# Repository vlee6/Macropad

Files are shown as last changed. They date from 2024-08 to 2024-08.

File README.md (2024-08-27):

# ATmega32U4 Macropad

For my first-ever PCB project, I've designed a 9 key low-profile macropad with a rotary encoder and oled screen. My intention was to keep costs minimal while retaining features found in most contemporary macropads. I began this journey after soldering my very own low-profile Lily58 build. While the Lily58 takes up minimal desk space and is very ergonomic, I found myself suffering from the small key count and lack of special features such as rotary encoders. Since I couldn't find any affordable alternative online, I set out to build my very own low-profile macropad to complete my desk setup.

Macropad Render

### Specs:
- ATmega32U4 Microcontroller
- 9 Kailh Hotswap Sockets (Low-profile Choc V1)
- WS2812B-2020 South-Facing Per-Key RGB Lighting
- Bourns PEC11R Rotary Encoder Switch
- 128x32 Oled I2C Display Module
- Easy-to-assemble 3D printed case
- (soon to be) VIA Compatible

### How is this different from the other macropads?
- Low-profile switches (like the Choc V1s I'm using in this build) are 40% shorter than regular mechanical keyboard switches.
- All components are directly soldered onto the board, no pro-micro (or equivalent devkit) necessary
- Per-key RGB lighting, not just underglow
- Estimated total cost of $30 to make, including all components and switches

### Assembly Instructions:
You will need...
- A switch for the reset buttom
- 9 Kailh Choc V1 switches of your choice
- 9 Choc V1 1U keycaps, I'm using clear Chosfox ones but MBK Choc keycaps will also work
- 9 WS2812B-2020 LEDs
- PEC11R-4015F-S0024 rotary encoder or equivalent
- A soldering setup
- Various electrical components that can be found on the [full parts list](https://docs.google.com/spreadsheets/d/1zmoziKfNFVxXU5fcjUS9J8uJfZayq2XkwIlthU0o6MI/edit?usp=sharing)

1. The board can be ordered with the production files in this repository (BOM and CPL included). If you are manufacturing with JLCPCB, have them assemble the bottom side (you will only need to solder the LEDs on the top side).
2. After printing out the top and bottom case from the STLs in this repository, they can be sandwiched to the PCB with four 4mm M2 screws (inserted from the bottom). If your PCB and case is aligned properly, the switches will snap in easily.

### Image Dump
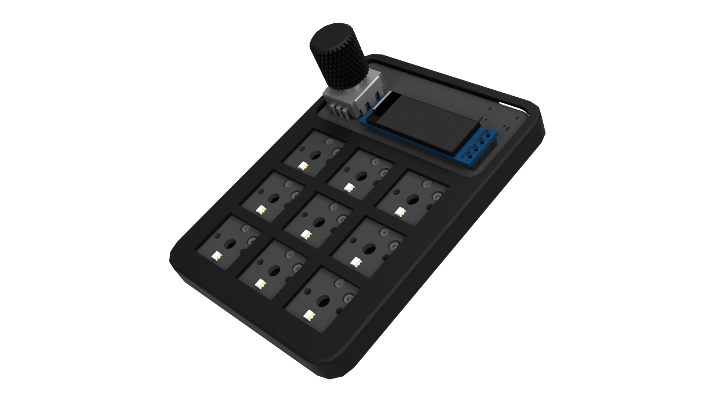
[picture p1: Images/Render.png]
Full Render

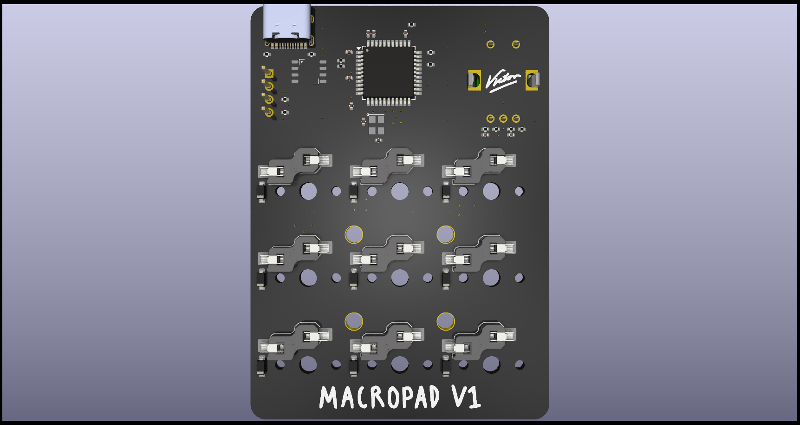
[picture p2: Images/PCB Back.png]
PCB Back

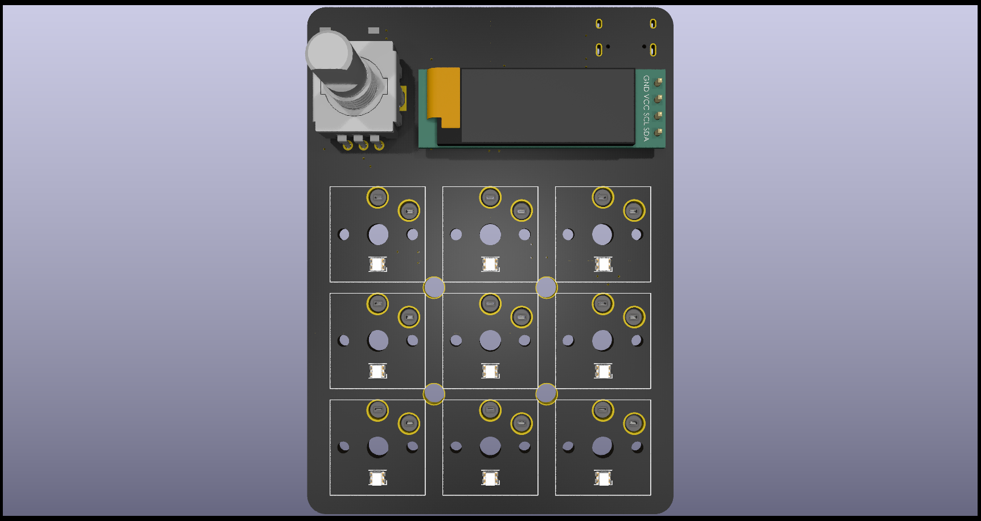
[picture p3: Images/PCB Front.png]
PCB Front


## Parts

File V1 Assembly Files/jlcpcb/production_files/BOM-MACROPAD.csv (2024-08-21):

Comment | Designator | Footprint | LCSC
USB6B1 | U1 | USB_Port_Protector_USB6B1 | C10508
16mghz | Y1 | Crystal_SMD_X322516MLB4SI | C13738
RotaryEncoder_Switch | SW2 | RotaryEncoder_Bourns_PEC11R-4xxxF-Sxxxx | C143789
10n | C7,C9 | C_0402_1005Metric | C15195
12p | C5,C6 | C_0402_1005Metric | C1547
USB_C_Receptacle_USB2.0_16P | J1 | USB_C_HRO_TYPE-C-31-M-12 | C165948
4.7u | C10 | C_0402_1005Metric | C23733
22 | R2,R3 | R_0402_1005Metric | C25092
10k | R1,R10,R11,R6,R7,R8,R9 | R_0402_1005Metric | C25744
5k1 | R4,R5 | R_0402_1005Metric | C25905
SW_Push | SW1 | SW_Tactile_TSB008A2530A | C2888954
4k7 | R12,R13 | R_0402_1005Metric | C2906941
100n | C1,C2,C3,C8 | C_0402_1005Metric | C307331
ATmega32U4-A | U3 | TQFP-44_10x10mm_P0.8mm | C44854
1u | C4 | C_0402_1005Metric | C52923
Keyswitch | S1,S2,S3,S4,S5,S6,S7,S8,S9 | Hotswap_Choc_V1_Plated_1.00u | C5333465
Diode | D1,D2,D3,D4,D5,D6,D7,D8,D9 | Diode_SOD-123 | C7420318
Display | J2 | SSD1306_LCD_Display_128x32
WS2812B-2020 | D13 | LED_WS2812B-2020_PLCC4_2.0x2.0mm
WS2812B-2020 | D12 | LED_WS2812B-2020_PLCC4_2.0x2.0mm
WS2812B-2020 | D16 | LED_WS2812B-2020_PLCC4_2.0x2.0mm
WS2812B-2020 | D14 | LED_WS2812B-2020_PLCC4_2.0x2.0mm
WS2812B-2020 | D17 | LED_WS2812B-2020_PLCC4_2.0x2.0mm
WS2812B-2020 | D11 | LED_WS2812B-2020_PLCC4_2.0x2.0mm
WS2812B-2020 | D15 | LED_WS2812B-2020_PLCC4_2.0x2.0mm
WS2812B-2020 | D18 | LED_WS2812B-2020_PLCC4_2.0x2.0mm
WS2812B-2020 | D10 | LED_WS2812B-2020_PLCC4_2.0x2.0mm

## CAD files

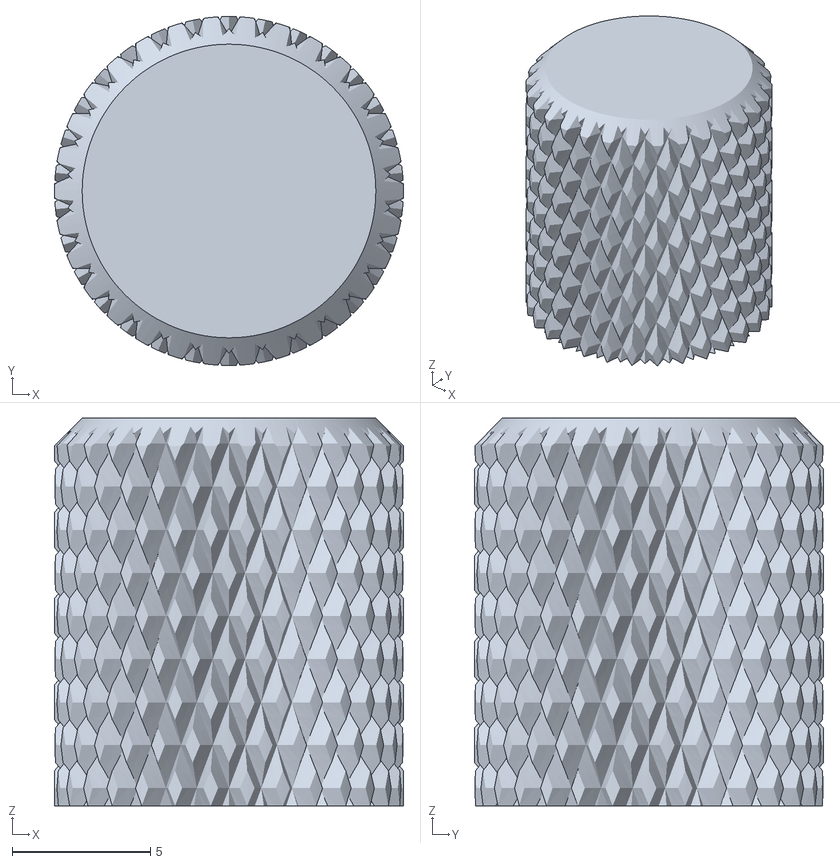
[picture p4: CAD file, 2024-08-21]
Macropad Case/Macropad Case - Knob.stl
12.6 x 12.6 x 14.0

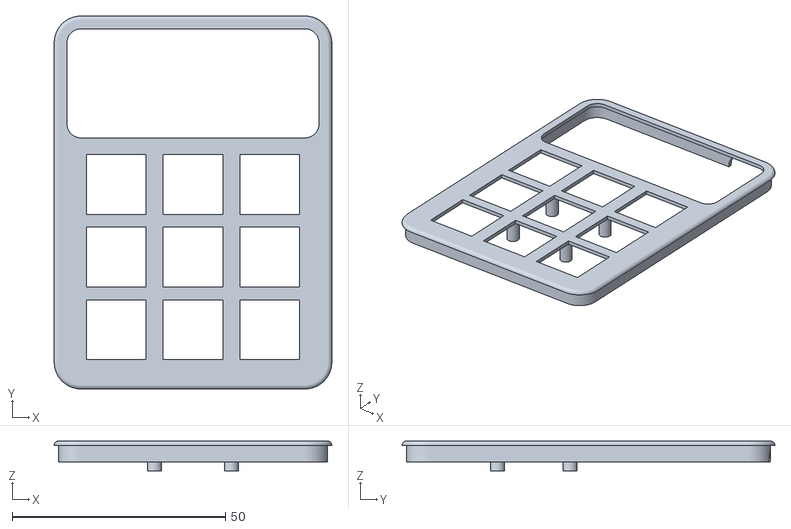
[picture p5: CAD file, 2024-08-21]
Macropad Case/Macropad Case - Top Case.stl
65.1 x 87.5 x 7.02

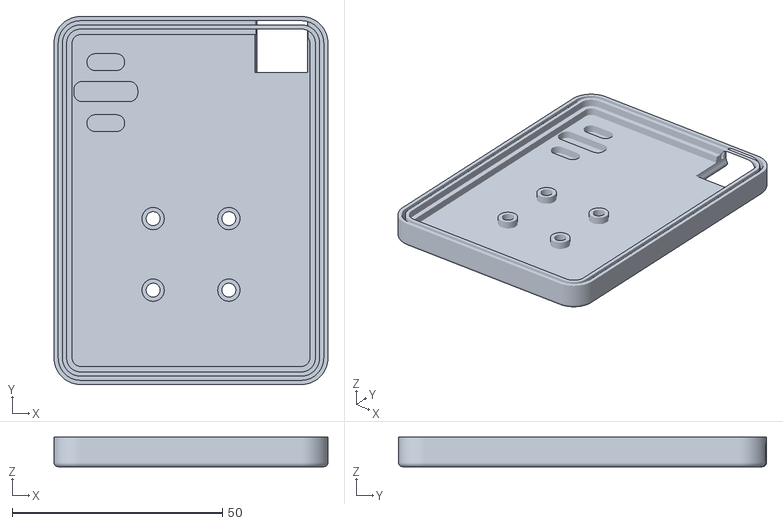
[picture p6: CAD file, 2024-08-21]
Macropad Case/Macropad Case - Bottom Case.stl
65.1 x 87.5 x 7.02

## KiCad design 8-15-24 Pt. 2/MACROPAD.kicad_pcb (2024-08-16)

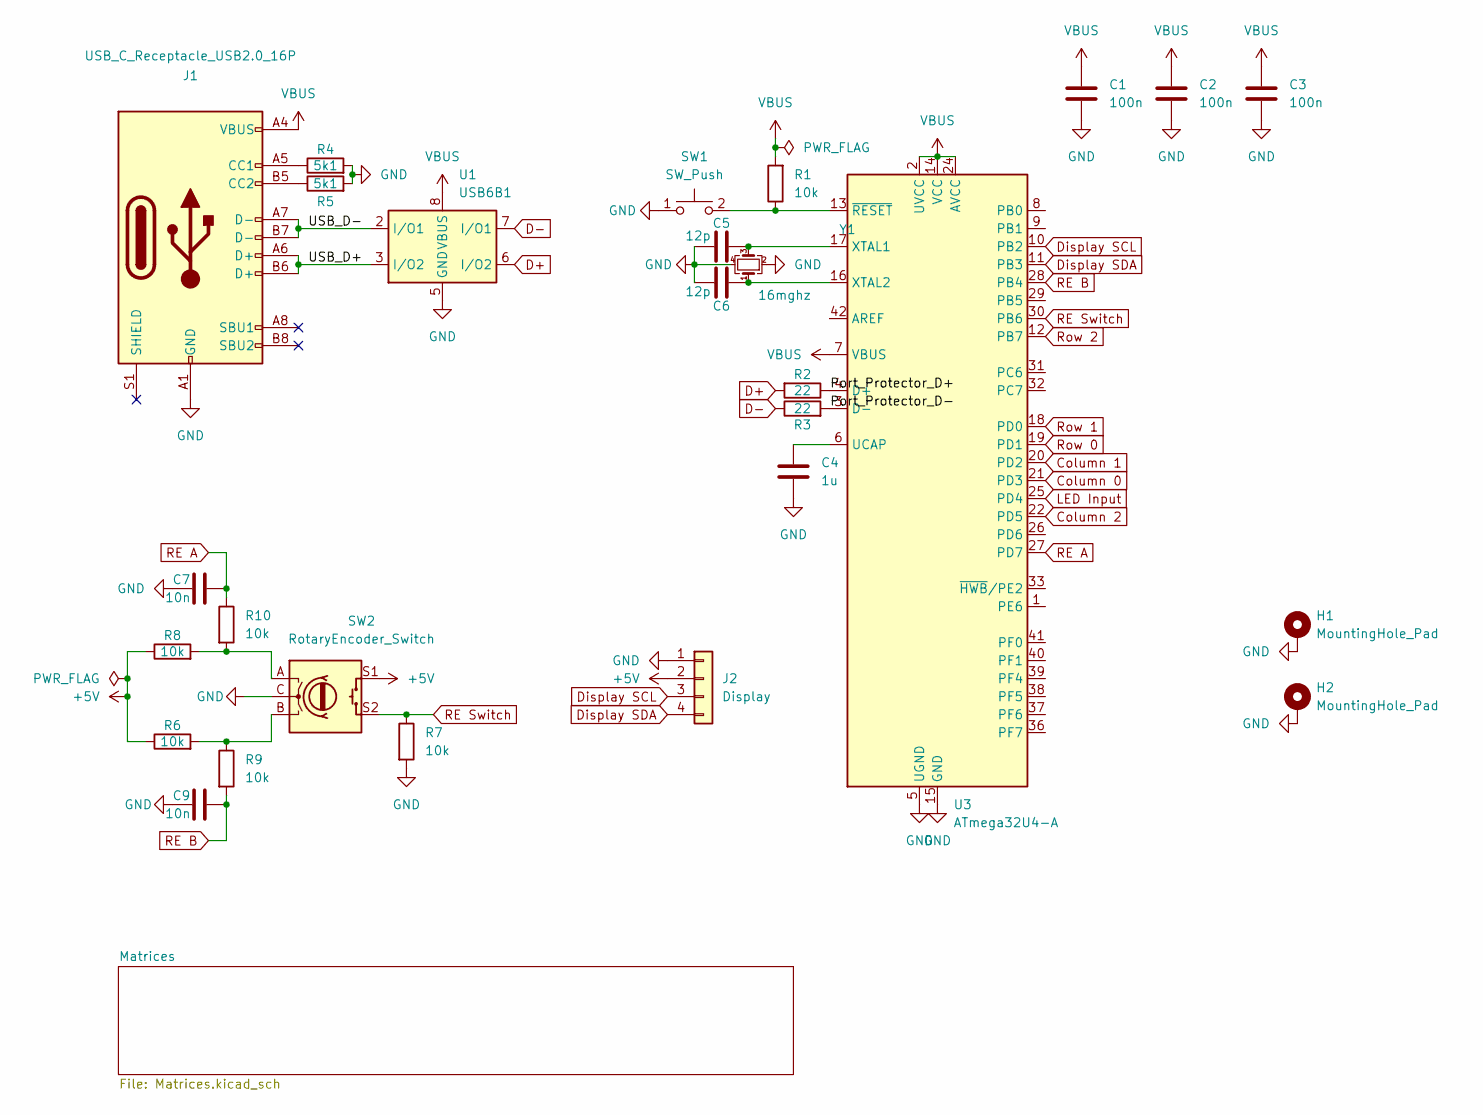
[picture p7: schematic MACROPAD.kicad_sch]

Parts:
C1, C2, C3: 100n; C_0402_1005Metric
C4: 1u; C_0402_1005Metric
C5, C6: 12p; C_0402_1005Metric
C7, C9: 10n; C_0402_1005Metric
H1, H2: MountingHole_Pad; MountingHole_KB
J1: USB_C_Receptacle_USB2.0_16P; USB_C_HRO_TYPE-C-31-M-12
J2: Display; SSD1306_LCD_Display_128x32
R1, R6, R7, R8, R9, R10: 10k; R_0402_1005Metric
R2, R3: 22; R_0402_1005Metric
R4, R5: 5k1; R_0402_1005Metric
SW1: SW_Push; SW_Tactile_TSB008A2530A
SW2: RotaryEncoder_Switch; RotaryEncoder_Bourns_PEC11R-4xxxF-Sxxxx
U1: USB6B1; USB_Port_Protector_USB6B1
U3: ATmega32U4-A; TQFP-44_10x10mm_P0.8mm
Y1: 16mghz; Crystal_SMD_X322516MLB4SI

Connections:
/Port_Protector_D+: R2.1, U3.4 (D+)
/Port_Protector_D-: R3.2, U3.3 (D-)
/USB_D+: J1.A6 (D+), J1.B6 (D+), U1.3 (I/O2)
/USB_D-: J1.A7 (D-), J1.B7 (D-), U1.2 (I/O1)
Column 0: U3.21 (PD3); also elsewhere on the board
Column 1: U3.20 (PD2); also elsewhere on the board
Column 2: U3.22 (PD5); also elsewhere on the board
D+: R2.2, U1.6 (I/O2)
D-: R3.1, U1.7 (I/O1)
Display SCL: J2.3, U3.10 (PB2)
Display SDA: J2.4, U3.11 (PB3)
GND: C1.2, C2.2, C3.2, C4.2, C5.2, C6.2, C7.1, C9.1, H1.1, H2.1, J1.A1 (GND), J1.A12 (GND), J1.B1 (GND), J1.B12 (GND), J2.1, R4.2, R5.2, R7.2, SW1.1, SW2.C, U1.4 (GND), U1.5 (GND), U3.5 (UGND), U3.15 (GND), U3.23 (GND), U3.35 (GND), U3.43 (GND), Y1.2, Y1.4; also elsewhere on the board
LED Input: U3.25 (PD4); also elsewhere on the board
unnamed: J1.A5 (CC1), R4.1
unnamed: J1.B5 (CC2), R5.1
unnamed: R6.2, R9.1, SW2.B
unnamed: R8.2, R10.2, SW2.A
unnamed: C4.1, U3.6 (UCAP)
unnamed: C5.1, U3.17 (XTAL1), Y1.3
unnamed: C6.1, U3.16 (XTAL2), Y1.1
unnamed: R1.1, SW1.2, U3.13 (~RESET)
RE A: C7.2, R10.1, U3.27 (PD7)
RE B: C9.2, R9.2, U3.28 (PB4)
RE Switch: R7.1, SW2.S2, U3.30 (PB6)
Row 0: U3.19 (PD1); also elsewhere on the board
Row 1: U3.18 (PD0); also elsewhere on the board
Row 2: U3.12 (PB7); also elsewhere on the board

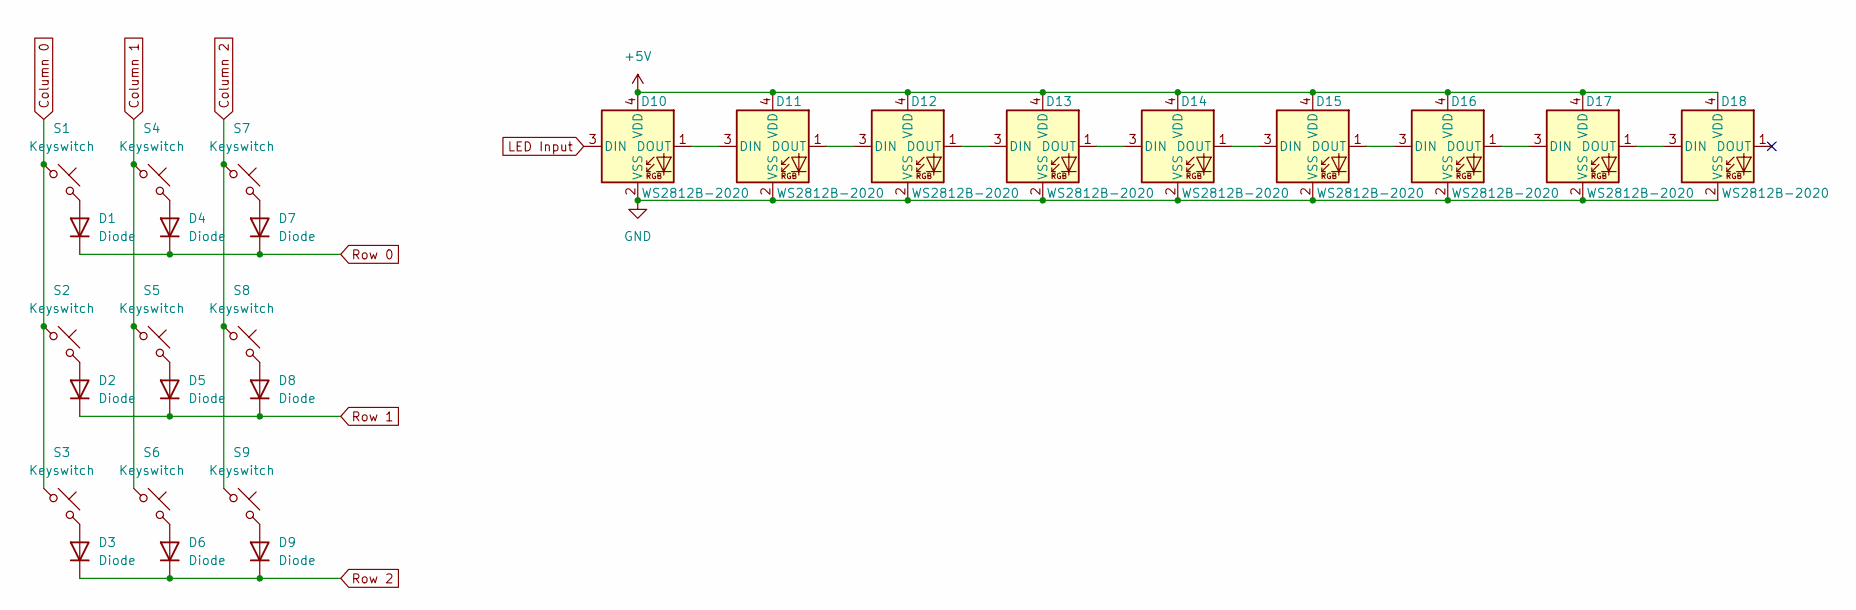
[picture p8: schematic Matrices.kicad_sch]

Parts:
D1, D2, D3, D4, D5, D6, D7, D8, D9: Diode; Diode_SOD-123
D10, D11, D12, D13, D14, D15, D16, D17, D18: WS2812B-2020; LED_WS2812B-2020_PLCC4_2.0x2.0mm
S1, S2, S3, S4, S5, S6, S7, S8, S9: Keyswitch; Hotswap_Choc_V1_Plated_1.00u

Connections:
Column 0: S1.1, S2.1, S3.1; also elsewhere on the board
Column 1: S4.1, S5.1, S6.1; also elsewhere on the board
Column 2: S7.1, S8.1, S9.1; also elsewhere on the board
GND: D10.2 (VSS), D11.2 (VSS), D12.2 (VSS), D13.2 (VSS), D14.2 (VSS), D15.2 (VSS), D16.2 (VSS), D17.2 (VSS), D18.2 (VSS); also elsewhere on the board
LED Input: D10.3 (DIN); also elsewhere on the board
unnamed: D1.2 (A), S1.2
unnamed: D2.2 (A), S2.2
unnamed: D3.2 (A), S3.2
unnamed: D4.2 (A), S4.2
unnamed: D5.2 (A), S5.2
unnamed: D6.2 (A), S6.2
unnamed: D7.2 (A), S7.2
unnamed: D8.2 (A), S8.2
unnamed: D9.2 (A), S9.2
unnamed: D10.1 (DOUT), D11.3 (DIN)
unnamed: D11.1 (DOUT), D12.3 (DIN)
unnamed: D12.1 (DOUT), D13.3 (DIN)
unnamed: D13.1 (DOUT), D14.3 (DIN)
unnamed: D14.1 (DOUT), D15.3 (DIN)
unnamed: D15.1 (DOUT), D16.3 (DIN)
unnamed: D16.1 (DOUT), D17.3 (DIN)
unnamed: D17.1 (DOUT), D18.3 (DIN)
Row 0: D1.1 (K), D4.1 (K), D7.1 (K); also elsewhere on the board
Row 1: D2.1 (K), D5.1 (K), D8.1 (K); also elsewhere on the board
Row 2: D3.1 (K), D6.1 (K), D9.1 (K); also elsewhere on the board

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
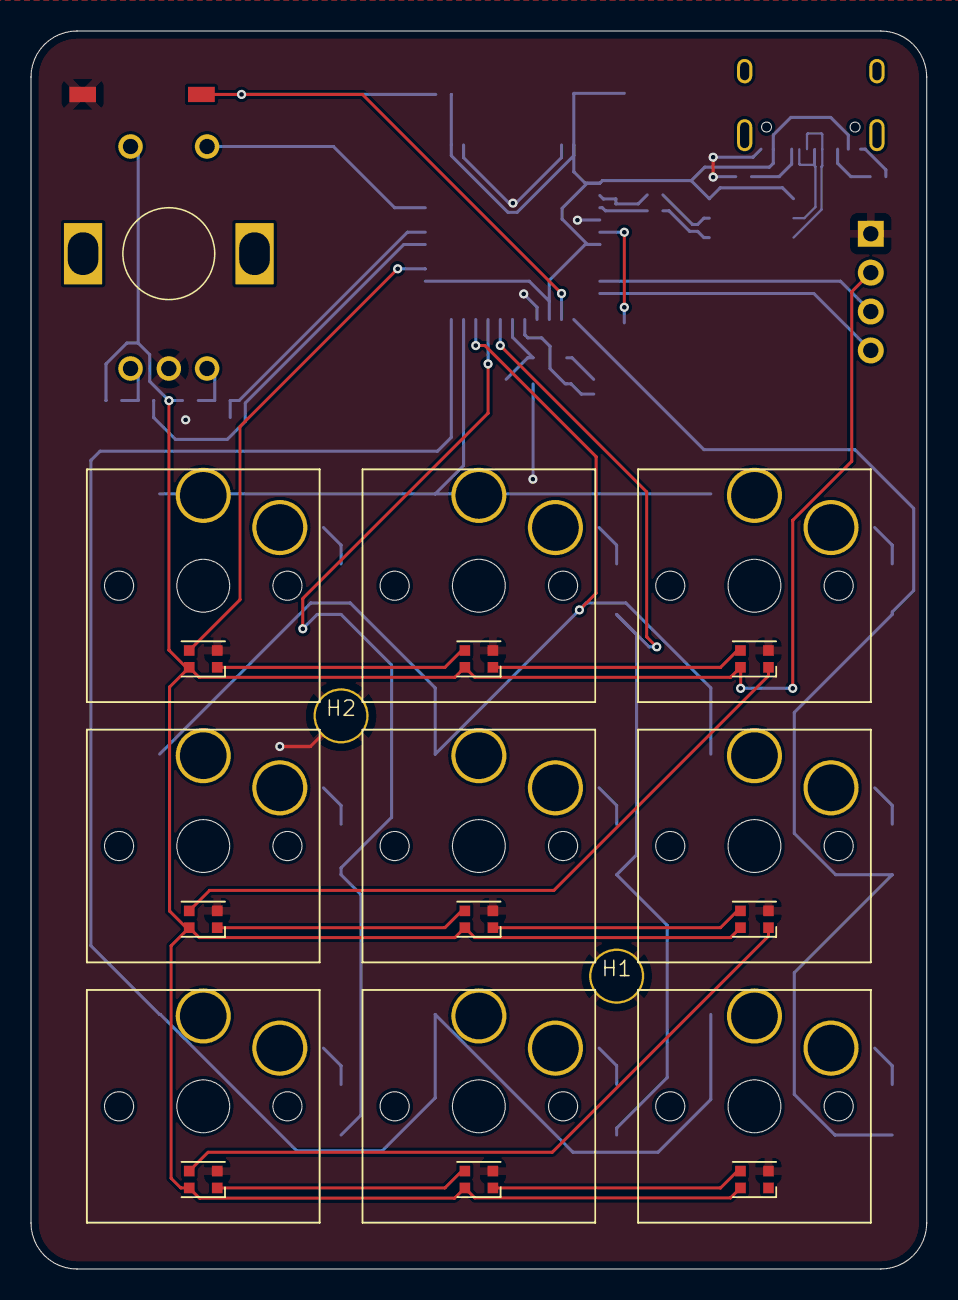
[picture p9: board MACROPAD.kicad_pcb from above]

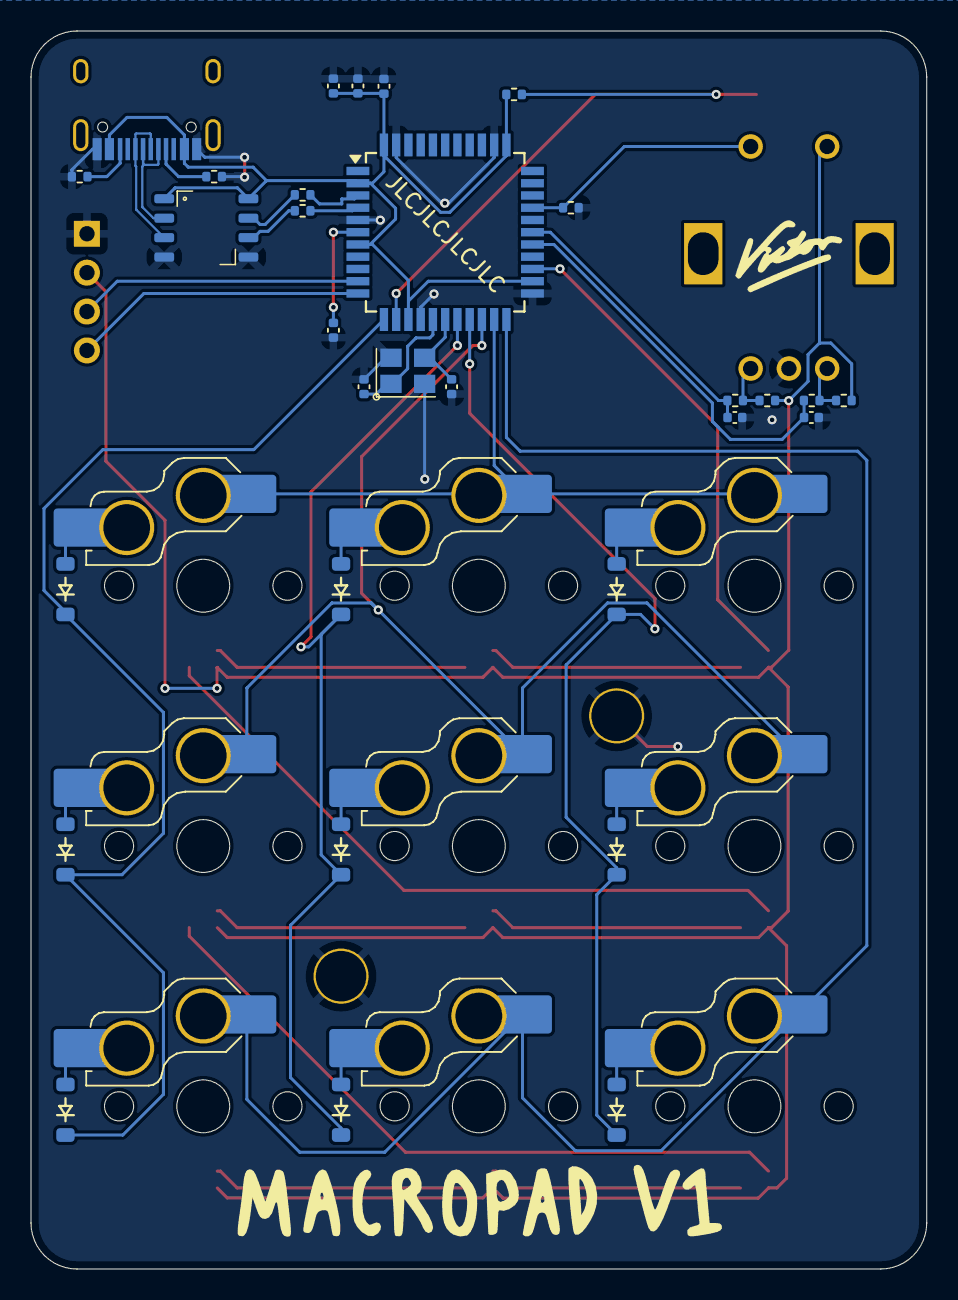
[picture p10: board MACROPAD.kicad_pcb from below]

Board: 2 copper layers, 58.5 x 80.9 mm, 54 parts (31 on the bottom side), 46 nets.

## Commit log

2024-08-12 Redoing macropad version control
    [MACROPAD.kicad_pcb, MACROPAD.kicad_sch, Matrices.kicad_sch]
2024-08-12 Finished routing traces and placing components
    [MACROPAD.kicad_pcb, MACROPAD.kicad_sch, Matrices.kicad_sch]
2024-08-13 Moved MCU and rounded edges
    [MACROPAD.kicad_pcb, MACROPAD.kicad_sch, Matrices.kicad_sch]
2024-08-13 Fixed issues, V1 complete
    [MACROPAD.kicad_pcb, MACROPAD.kicad_sch, Matrices.kicad_sch]
2024-08-13 Added gerbers, graphics, fixed RE button
    [MACROPAD-B_Cu.gbr, MACROPAD-B_Mask.gbr, MACROPAD-B_Paste.gbr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]
2024-08-16 Started fixing bugs
    [MACROPAD.kicad_pcb, MACROPAD.kicad_sch, Matrices.kicad_sch]
2024-08-16 Need to figure out how to connect +5v nest to VBUS
    [MACROPAD.kicad_pcb, MACROPAD.kicad_sch, Matrices.kicad_sch]
2024-08-21 Finished design and sent out files for assembly
    [BOM-MACROPAD.csv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]
2024-08-21 Added case STLs
    https://cad.onshape.com/documents/7c0fd680344a7fb116117cb6/w/ed0fe4f0ce8d5604549aa17e/e/687a8a392ee8c72c6ad0a9a0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
    [Part Studio 1 - Bottom Case.stl, Part Studio 1 - Knob.stl, Part Studio 1 - Top Case.stl]
2024-08-21 Added case to images
2024-08-21 Need to redo cases
    [Part Studio 1 - Bottom Case.stl, Part Studio 1 - Knob.stl, Part Studio 1 - Top Case.stl]
2024-08-21 Added updated case models
    [Macropad Case - Bottom Case.stl, Macropad Case - Knob.stl, Macropad Case - Top Case.stl]
